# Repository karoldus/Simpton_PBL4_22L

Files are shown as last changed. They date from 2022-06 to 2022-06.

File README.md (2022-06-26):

# Simpton - smart wireless button with RFID

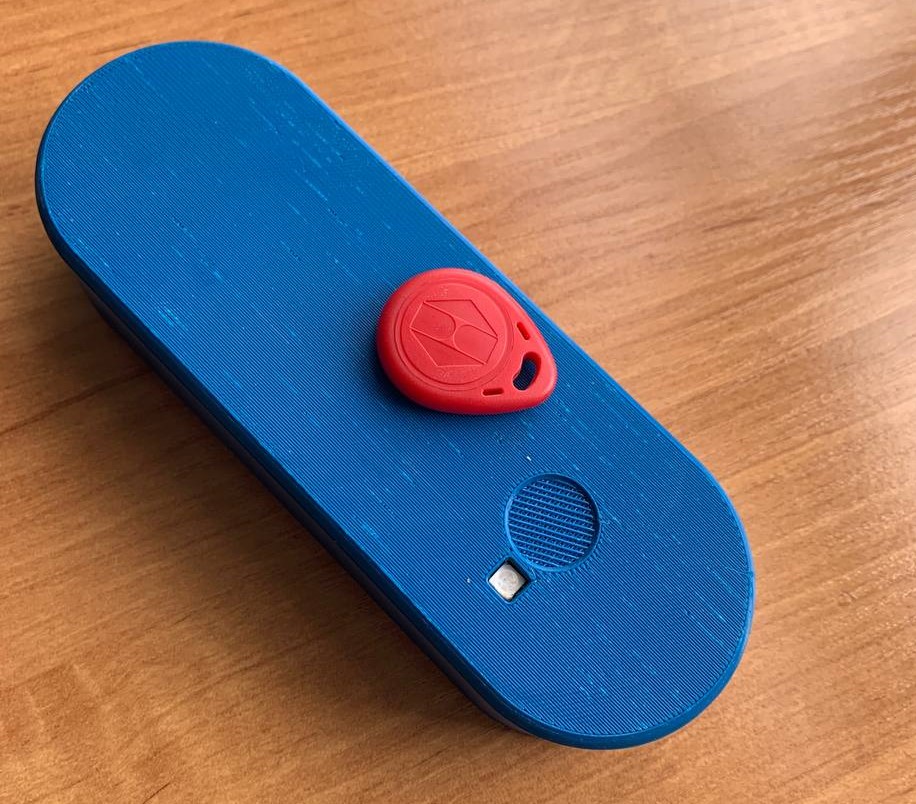
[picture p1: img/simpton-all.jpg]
Simpton


## Overview

Simpton is a wireless (Bluetooth LE) button with RFID reader. It can be used to manage access to buildings without changes to the structure of the building.

It was created by Karol Duszczyk, Michał Twarowski and Kamil Wieteska on PBL-4 classes (spring 2022) as part of the Internet of Things studies at the Warsaw University of Technology.

# Hardware

## Technology used

### Tools
- Altium Designer
- Fushion 360
- Soldering iron, soldering oven
- 3D printer

### Parts
- microcontroller STM32L031G6U7
- capacitive button IQS227B00000000TSR
- 125 kHz RFID reader MLX90109CDC-AAA-000-SP
- voltage regulator ISL91110IRNZ-T7A
- battery gauge MAX17201G+T
- BLE module RN4870-V/RM118
- RGB diode
- PPTC, RFID antenna, 18650 battery, R, L, C, connectors...

## Results

### Schematic

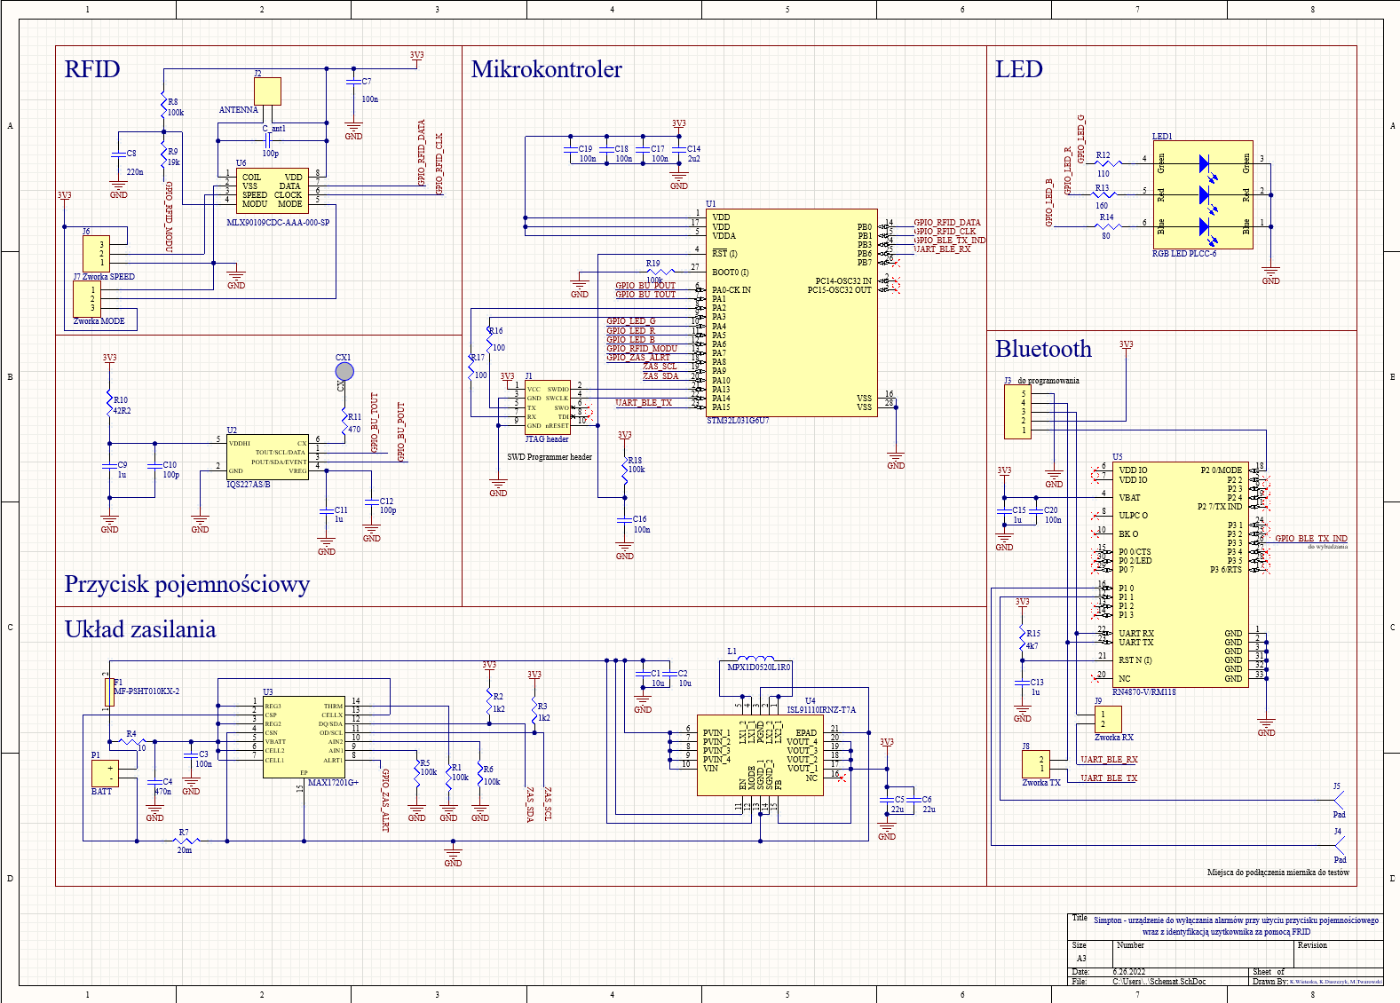
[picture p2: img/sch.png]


Schematic was created in Altium Designer. It has 6 parts:
- capacitive button, LED by Karol
- RFID by Michał
- power module by Kamil
- BLE, microcontroller by all together

### PCB

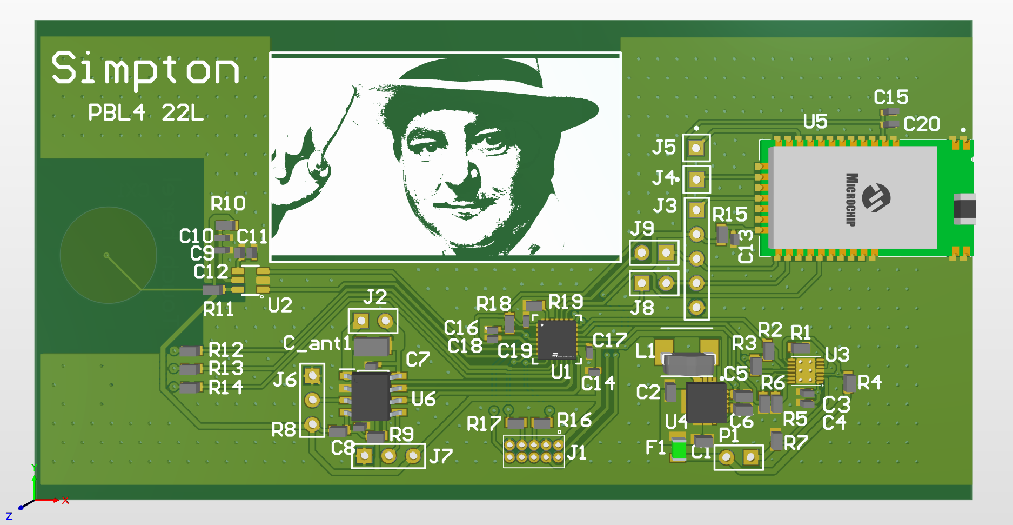
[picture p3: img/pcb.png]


## Bugs found

- There is an unresolved problem with a battery gauge. It can't connect to uC by I2C. Probably wrong connection to one of the VCC pins (3.3 V instead of 1.8 V).
- There should be added switch to disconnect battery.

# Software

## Technologies used
- C language
- STM32CubeIDE
- Segger J-Link EDU

## Code

Every device module has it's own driver and library for it's hardware part.

Code modules:
- state_machine - simple state machine by Karol
- rfid_driver & mlx90109cdc - RFID library by Michał
- gauge_driver & max17201 - gauge library by Kamil
- ble_driver & rn4870 - BLE library by Karol

Working cycle:
1. Sleep
2. Wake up when button pressed (by interrupt)
3. Power on BLE and blink blue LED
4. Power on RFID reader and wait up to 10 s to read RFID card
    1. If no card was presented turn off RFID and BLE, blink red led and go to sleep (return to point 1)
5. Blink green LED once. If there isn't BLE connection wait up to 10 s to get it.
    1. If there still isn't connection turn off RFID and BLE, blink red led twice and go to sleep (return to point 1)
6. Send RFID tag number by BLE and blink green LED twice
7. (not implemented) Read battery status from gauge and send it by BLE
8. Turn off RFID and BLE and go to sleep (return to point 1)

## Results

Simpton movie

We created working prototype without a power gauge.

## Bugs found

- STM32L031G6U7 has too low Flash memory.
- UART (used to communicate with BLE) has unresolved problem with receiving data (sometimes receives and sometimes not).

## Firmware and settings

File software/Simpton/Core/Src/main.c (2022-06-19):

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
/* Includes ------------------------------------------------------------------*/
#include "main.h"

 TIM_HandleTypeDef htim21;

UART_HandleTypeDef huart2;

/* USER CODE BEGIN PV */

StateMachine stateMachine;

BLE ble_device;

RFID_Data reader;

//GAUGE gauge;

//uint8_t gaugeDataReady; //for external interrupt

/* USER CODE END PV */

void SystemClock_Config(void);
static void MX_GPIO_Init(void);
static void MX_USART2_UART_Init(void);
static void MX_TIM21_Init(void);
/* USER CODE BEGIN 0 */


void HAL_GPIO_EXTI_Callback(uint16_t GPIO_Pin)
{
  if (GPIO_Pin == GPIO_BU_POUT_Pin && stateMachine.programState == SLEEP_STATE)
  {
	  // button interrupt

	  SystemClock_Config ();
	  HAL_ResumeTick();
	  HAL_PWR_DisableSleepOnExit();

	  // WAKE UP

	  stateMachine.programState = WAKING_UP_STATE;
  }
  else if (GPIO_Pin == GPIO_RFID_CLK_Pin && stateMachine.programState == WAITING_FOR_RFID_STATE)
  {	// RFID CLK interrupt
	  if(HAL_GetTick() - stateMachine.RFIDStartTime >= RFID_TIMEOUT)
		  HAL_GPIO_WritePin(GPIO_RFID_MODU_GPIO_Port, GPIO_RFID_MODU_Pin, 1);

	  // read rfid
	  RFID_Interrupt_handler(&reader,&htim21);
  }
//  else if ( GPIO_Pin == GPIO_ZAS_ALERT_Pin )
//  {   // gauge interrupt
//		gaugeDataReady = 1;
//  }
}



/* USER CODE END 0 */

/**
  * @brief  The application entry point.
  * @retval int
  */
int main(void)
{
  /* USER CODE BEGIN 1 */

	stateMachine.programState = SLEEP_STATE;

  /* USER CODE END 1 */

  /* MCU Configuration--------------------------------------------------------*/

  /* Reset of all peripherals, Initializes the Flash interface and the Systick. */
  HAL_Init();

  /* Configure the system clock */
  SystemClock_Config();

  /* Initialize all configured peripherals */
  MX_GPIO_Init();
  MX_USART2_UART_Init();
  MX_TIM21_Init();
  /* USER CODE BEGIN 2 */

  Machine_Initialise(&stateMachine, &ble_device, &reader, GPIO_LED_R_GPIO_Port, GPIO_LED_R_Pin, GPIO_LED_G_GPIO_Port, GPIO_LED_G_Pin, GPIO_LED_B_GPIO_Port, GPIO_LED_B_Pin, GPIO_RFID_MODU_GPIO_Port, GPIO_RFID_MODU_Pin);

  RFID_Initialise(&reader, GPIO_RFID_DATA_GPIO_Port, GPIO_RFID_CLK_GPIO_Port, GPIO_RFID_MODU_GPIO_Port, GPIO_RFID_DATA_Pin, GPIO_RFID_CLK_Pin, GPIO_RFID_MODU_Pin);
  HAL_TIM_Base_Start(&htim21);

  BLE_Initialise( &ble_device, &huart2, GPIO_BLE_TX_IND_GPIO_Port, GPIO_BLE_TX_IND_Pin);

  //Gauge_initialise(&gauge, &hi2c1);

  /* USER CODE END 2 */

  /* Infinite loop */
  /* USER CODE BEGIN WHILE */

  HAL_GPIO_WritePin(GPIO_RFID_MODU_GPIO_Port, GPIO_RFID_MODU_Pin, 1);

  while (1)
  {

	  switch(stateMachine.programState)
	  {
	  	  case WAKING_UP_STATE:
	  		  waking_up(&stateMachine);
	  		  break;

	  	  case WAITING_FOR_RFID_STATE:
	  		  if(reader.tag != 0) // got tag - condition to do
			  {
	  			  rfid_found(&stateMachine);
	  			  BLE_Send(&ble_device, "OK\n\r");

			  }
			  else if(HAL_GetTick() - stateMachine.RFIDStartTime >= RFID_TIMEOUT)
			  {
				  // RFID Timeout
				  rfid_not_found(&stateMachine);
			  }

	  		  break;

	  	  case RFID_FOUND_STATE:
	  		  if(BLE_is_connected(&ble_device) == HAL_OK && ble_device.connection == 1) // got connection - condition to do
	  		  //if(1) // FAKE BLE TEST
			  {
	  			ble_found(&stateMachine);
			  }
			  else if(HAL_GetTick() - stateMachine.RFIDStartTime >= BLE_TIMEOUT)
			  {
				  // BLE Timeout
				  ble_not_found(&stateMachine);
			  }

	  		  break;
	  }

    /* USER CODE END WHILE */

    /* USER CODE BEGIN 3 */
  }
  /* USER CODE END 3 */
}

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


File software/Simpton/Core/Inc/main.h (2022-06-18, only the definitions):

#define GPIO_BU_POUT_Pin GPIO_PIN_0
#define GPIO_BU_POUT_GPIO_Port GPIOA
#define GPIO_BU_POUT_EXTI_IRQn EXTI0_1_IRQn
#define GPIO_BU_TOUT_Pin GPIO_PIN_1
#define GPIO_BU_TOUT_GPIO_Port GPIOA
#define GPIO_LED_B_Pin GPIO_PIN_4
#define GPIO_LED_B_GPIO_Port GPIOA
#define GPIO_LED_R_Pin GPIO_PIN_5
#define GPIO_LED_R_GPIO_Port GPIOA
#define GPIO_LED_G_Pin GPIO_PIN_6
#define GPIO_LED_G_GPIO_Port GPIOA
#define GPIO_RFID_MODU_Pin GPIO_PIN_7
#define GPIO_RFID_MODU_GPIO_Port GPIOA
#define GPIO_RFID_DATA_Pin GPIO_PIN_0
#define GPIO_RFID_DATA_GPIO_Port GPIOB
#define GPIO_RFID_CLK_Pin GPIO_PIN_1
#define GPIO_RFID_CLK_GPIO_Port GPIOB
#define GPIO_RFID_CLK_EXTI_IRQn EXTI0_1_IRQn
#define GPIO_ZAS_ALERT_Pin GPIO_PIN_8
#define GPIO_ZAS_ALERT_GPIO_Port GPIOA
#define GPIO_BLE_TX_IND_Pin GPIO_PIN_3
#define GPIO_BLE_TX_IND_GPIO_Port GPIOB

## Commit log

2022-05-13 edit LPUART config + edit printf for debug
2022-05-21 Ready to tests
    Interrupt handler, pins conf
2022-05-21 printf from interrupt to loop
2022-05-27 Ports, interrupts
    - interrupts on BUTTON_POUT, RFID_CLK and ZAS_ALERT
    - button example
2022-06-01 power on and off
2022-06-09 get status from main to driver
2022-06-11 clean code, machine + ble (without power on) work
2022-06-11 return tagId, delete DMA, reduce FLASH usage by removing printf
2022-06-26 sch & pcb
    [PBL4_SIMPTON.PrjPcb, SIMPTON_PCB.PcbDoc, Schemat.SchDoc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]

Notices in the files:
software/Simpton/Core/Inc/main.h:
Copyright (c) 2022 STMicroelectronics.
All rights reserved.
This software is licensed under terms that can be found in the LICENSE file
